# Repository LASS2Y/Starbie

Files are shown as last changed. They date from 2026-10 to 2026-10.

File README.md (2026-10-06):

# Starbie

A tiny motion-controlled digital pet, basically a desktop Tamagotchi. Totally not a Starboy.

Starbie lives on a small PCB built around a Seeed Studio XIAO ESP32-C3. It shows its face and mood on a 0.96" OLED screen, reacts when you tilt or shake it thanks to an MPU6050 accelerometer/gyroscope, notices the temperature and humidity of the room with a DHT11, and you interact with it through two mechanical Cherry MX keys.

This is my starter project for Hack Club's **Half Life** PCB design program.

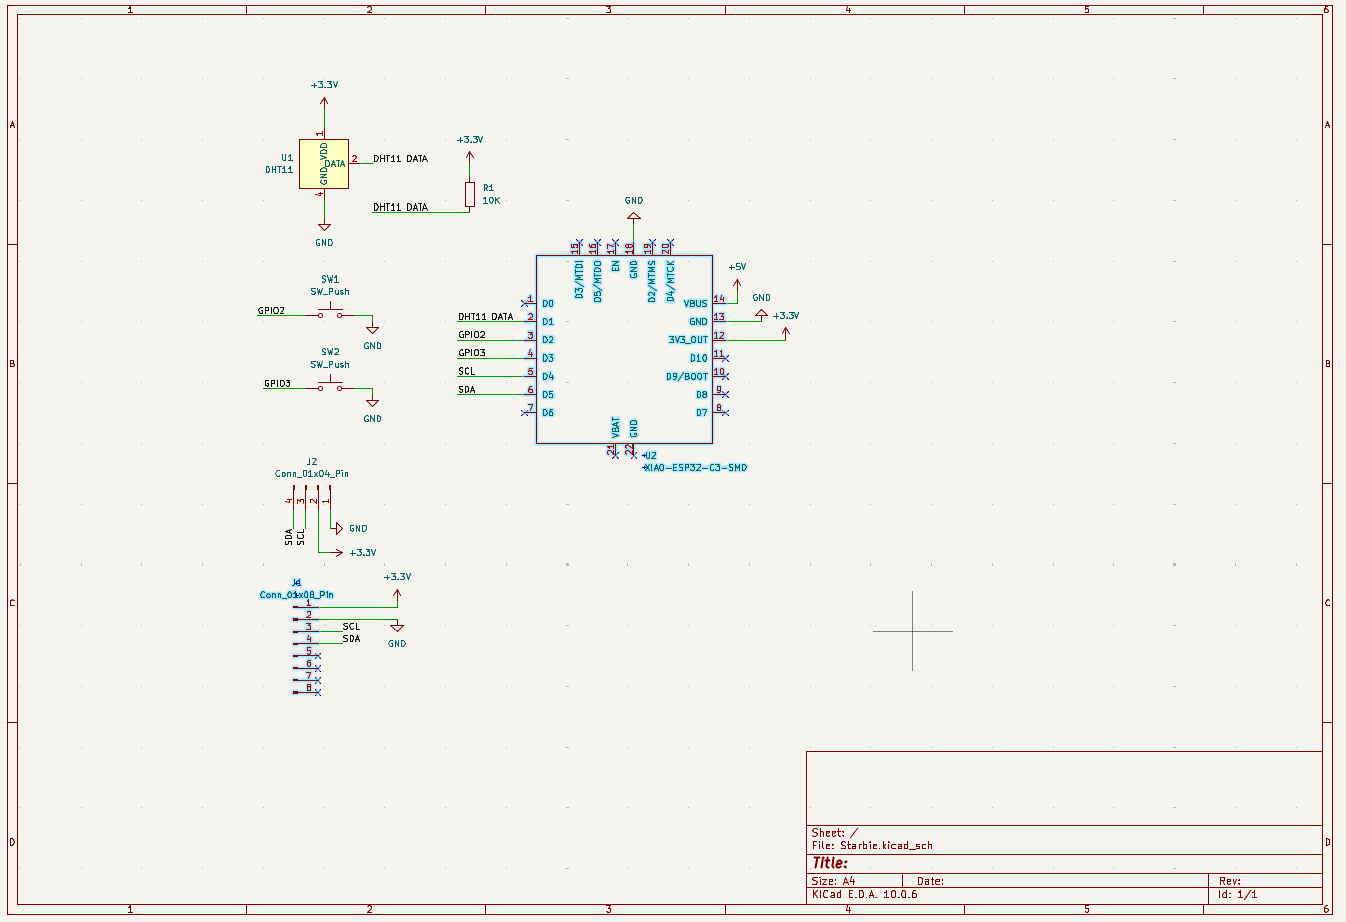
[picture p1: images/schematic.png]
Starbie schematic


## How it works

- **Brain:** the XIAO ESP32-C3 runs the firmware and drives everything.
- **Screen:** the SSD1306 128x64 OLED shares an I2C bus with the MPU6050.
- **Motion:** the MPU6050 detects tilts, shakes and taps. That's how you play with Starbie.
- **Environment:** the DHT11 measures temperature and humidity, so Starbie can tell when it's too hot or too cold.
- **Buttons:** two Cherry MX switches for feeding, playing and navigating menus.
- **Power:** USB-C through the XIAO.

## Pinout

| XIAO pin | Connected to |
|---|---|
| D1 | DHT11 data (10 kΩ pull-up to 3.3V) |
| D2 | SW1 (to GND) |
| D3 | SW2 (to GND) |
| D4 / SDA | OLED + MPU6050 SDA |
| D5 / SCL | OLED + MPU6050 SCL |
| 3V3 | OLED, MPU6050, DHT11 |
| GND | Common ground |

The buttons pull the pin to GND when pressed, so the firmware uses the ESP32's internal pull-ups.

## Bill of materials

| Ref | Part | Qty |
|---|---|---|
| U2 | Seeed Studio XIAO ESP32-C3 | 1 |
| J2 | 0.96" SSD1306 OLED, 128x64, I2C | 1 |
| J1 | GY-521 MPU6050 module (1x08 header) | 1 |
| U1 | DHT11 temperature & humidity sensor | 1 |
| SW1, SW2 | Cherry MX switch + DSA keycap | 2 |
| R1 | 10 kΩ resistor (THT) | 1 |

## Repository layout

```
Starbie.kicad_pro     KiCad project
Starbie.kicad_sch     Schematic
Starbie.kicad_pcb     PCB layout
Week 1 Care Package/  Symbols, footprints and 3D models used by the project
firmware/             Firmware (coming soon)
images/               Screenshots (PCB render coming once routing is done)
```

## Status

- [x] Schematic
- [x] Footprints assigned
- [ ] Board outline and component placement
- [ ] Routing
- [ ] 3D render
- [ ] Firmware
- [ ] Fabrication files (Gerbers)

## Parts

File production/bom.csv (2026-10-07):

Reference | Qty | Value | DNP | Exclude from BOM | Exclude from Board | Exclude from Simulation | Exclude from Position Files | Footprint | Datasheet
J1 | 1 | Conn_01x08_Pin |  |  |  |  | ${EXCLUDE_FROM_POS_FILES} | Connector_PinHeader_2.54mm:PinHeader_1x08_P2.54mm_Vertical
J2 | 1 | Conn_01x04_Pin |  |  |  |  | ${EXCLUDE_FROM_POS_FILES} | Imported Parts:Display_128x64_096_I2C
R1 | 1 | 10K |  |  |  |  | ${EXCLUDE_FROM_POS_FILES} | Resistor_THT:R_Axial_DIN0204_L3.6mm_D1.6mm_P7.62mm_Horizontal
SW1,SW2 | 2 | SW_Push |  |  |  |  | ${EXCLUDE_FROM_POS_FILES} | Button_Switch_Keyboard:SW_Cherry_MX_1.00u_PCB
U1 | 1 | DHT11 |  |  |  |  | ${EXCLUDE_FROM_POS_FILES} | Sensor:Aosong_DHT11_5.5x12.0_P2.54mm | http://akizukidenshi.com/download/ds/aosong/DHT11.pdf
U2 | 1 | XIAO-ESP32-C3-SMD |  |  |  |  | ${EXCLUDE_FROM_POS_FILES} | Imported Parts:XIAO-ESP32-C6-DIP

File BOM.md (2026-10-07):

# Starbie — bill of materials

<!-- Generated by Half Life from project cmuv4g8x80dem01smvfayf5wf. Edits here are overwritten on the next sync. -->
<!-- Generated: 2026-10-07T19:32:48.326Z -->

> [!NOTE]
> This parts list is mirrored from [Half Life](https://halflife.hackclub.com). Editing it here will not change the platform's copy, and the next sync overwrites this file.

| Week | Tier | Parts funding |
| --- | --- | --- |
| Week 1 | Tier 1 | $30.00 |

| Part | What it's for | Qty | Unit | Total | Vendor |
| --- | --- | --- | --- | --- | --- |
| Conn_01x08_Pin | — | 1 | $0.00 | $0.00 | — |
| Conn_01x04_Pin | — | 1 | $0.00 | $0.00 | — |
| 10K | — | 1 | $0.00 | $0.00 | — |
| SW_Push | — | 2 | $0.00 | $0.00 | — |
| DHT11 | — | 1 | $0.00 | $0.00 | — |
| XIAO-ESP32-C3-SMD | — | 1 | $0.00 | $0.00 | — |
| **Parts subtotal** | — | — | — | **$0.00** | — |
| **Tax & shipping** | — | — | — | **$0.00** | — |
| **Total** | — | — | — | **$0.00** | — |

$30.00 left of the tier's funding.

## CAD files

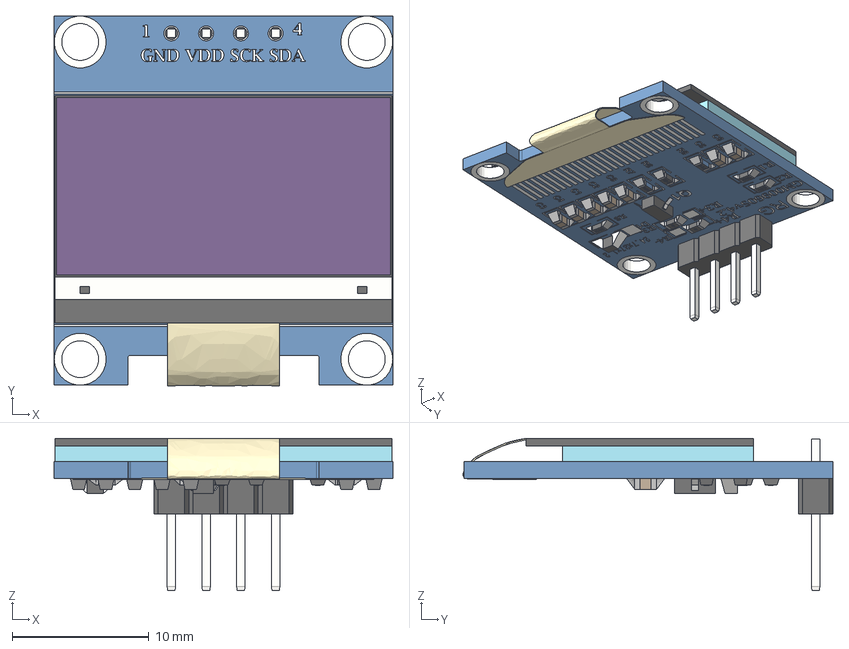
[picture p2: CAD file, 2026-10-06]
Week 1 Care Package/3D Models/0.96'' OLED Display.step
24.8 x 27.1 x 11.1 mm

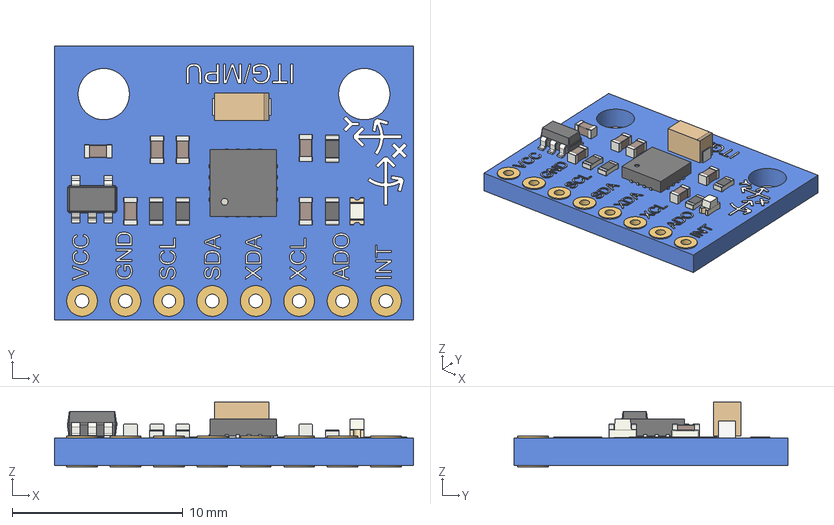
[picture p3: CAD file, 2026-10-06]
Week 1 Care Package/3D Models/GY-521_MPU6050 Accelerometer.step
21.0 x 16.0 x 3.80 mm
PCB
trou1
trou002
trou003
trou004
trou005
trou006
trou007
trou008
Text_X
Symb_Y
Symb_X
Text_Y
Text_VCC
Text_GND
Text_SCL
Text_SDA
Text_XDA
Text_XCL
Text_ADO
Text_INT
R_0603_1608Metric
R_0603_1608Metric001
R_0603_1608Metric002
R_0603_1608Metric003
C_0603_1608Metric
C_0603_1608Metric001
C_0603_1608Metric002
C_0603_1608Metric003
Corps002
Corps001 (Mirror #1)
C_0603_1608Metric004
C_0603_1608Metric005
LED_0603_1608Metric_Castellated
QFN_16_1EP_4x4mm_P065mm_EP21x21mm
Text_ITGMPU
SOT_23_5
Corps001

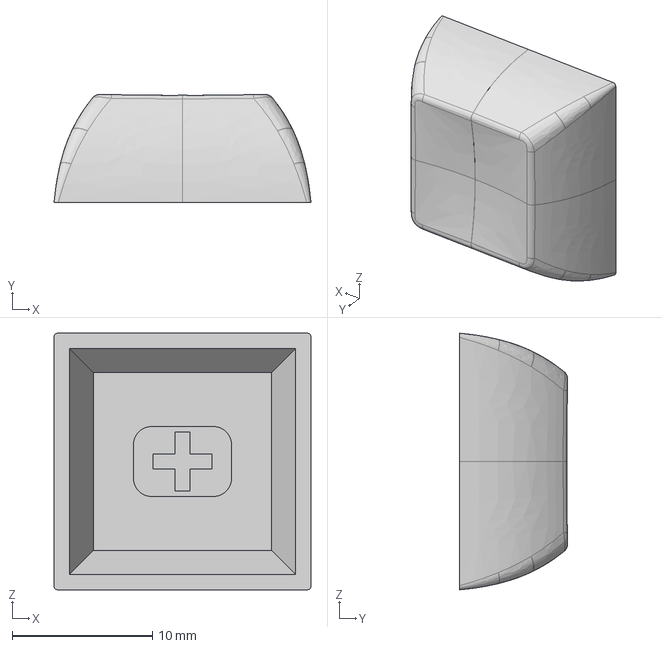
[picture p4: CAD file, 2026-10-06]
Week 1 Care Package/3D Models/DSA_Keycap_CherryMX.step
18.3 x 7.69 x 18.3 mm

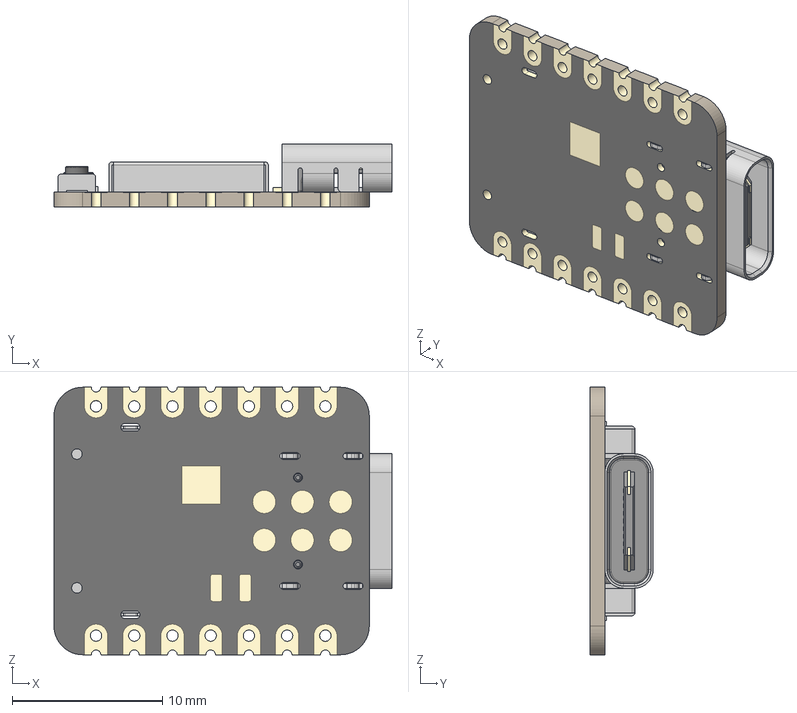
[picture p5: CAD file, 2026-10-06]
Week 1 Care Package/3D Models/Seeed Studio XIAO-ESP32-C3.step
22.5 x 4.21 x 17.8 mm
BOSS-EXTRUDE14_8_
BOSS-EXTRUDE7_4_
BOSS-EXTRUDE7_3_
BOSS-EXTRUDE14_4_
BOSS-EXTRUDE14_2_
BOSS-EXTRUDE14_11_
BOSS-EXTRUDE7_7_
BOSS-EXTRUDE14_9_
BOSS-EXTRUDE14_3_
BOSS-EXTRUDE14_7_
MIRROR2
BOSS-EXTRUDE14_5_
BOSS-EXTRUDE14_12_
BOSS-EXTRUDE7_8_
BOSS-EXTRUDE7_1_
BOSS-EXTRUDE14_10_
BOSS-EXTRUDE7_9_
BOSS-EXTRUDE14_6_
BOSS-EXTRUDE14_1_
BOSS-EXTRUDE7_6_
BOSS-EXTRUDE7_2_
CUT-EXTRUDE5
BOSS-EXTRUDE7_5_
U.FL Connector v1
Button (1) x 2
Shield

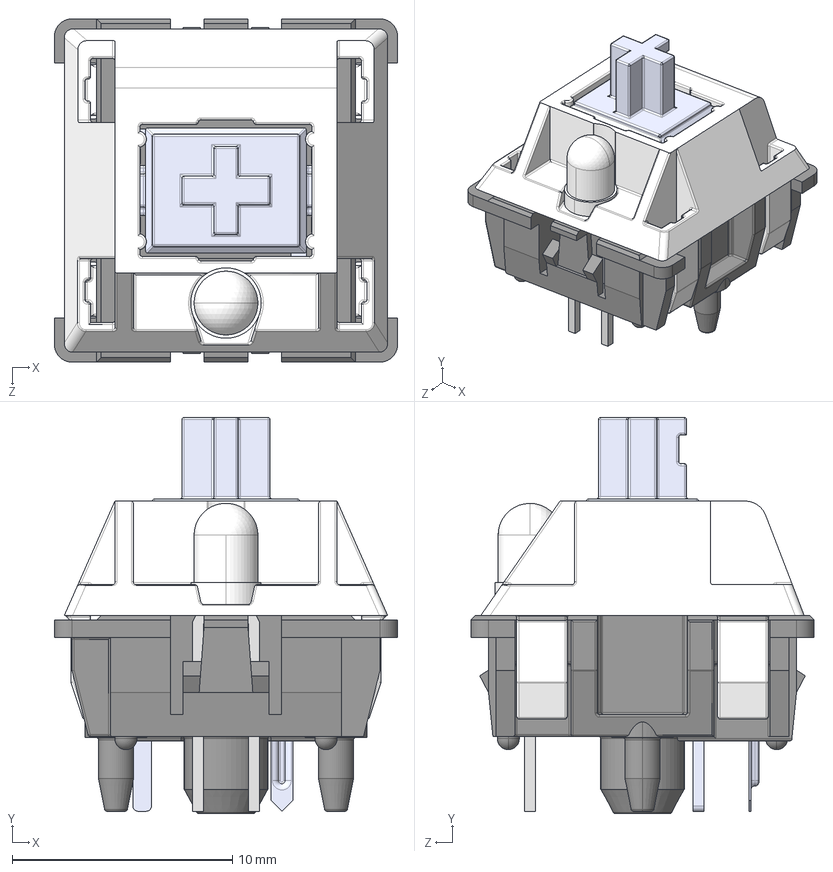
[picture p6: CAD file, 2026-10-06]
Week 1 Care Package/3D Models/Cherry MX.STEP
15.6 x 18.0 x 15.6 mm
Bottom
Pulsador
Top
Pieza5^Cherry MX
Pin1
Pin2
Led 3mm_trans

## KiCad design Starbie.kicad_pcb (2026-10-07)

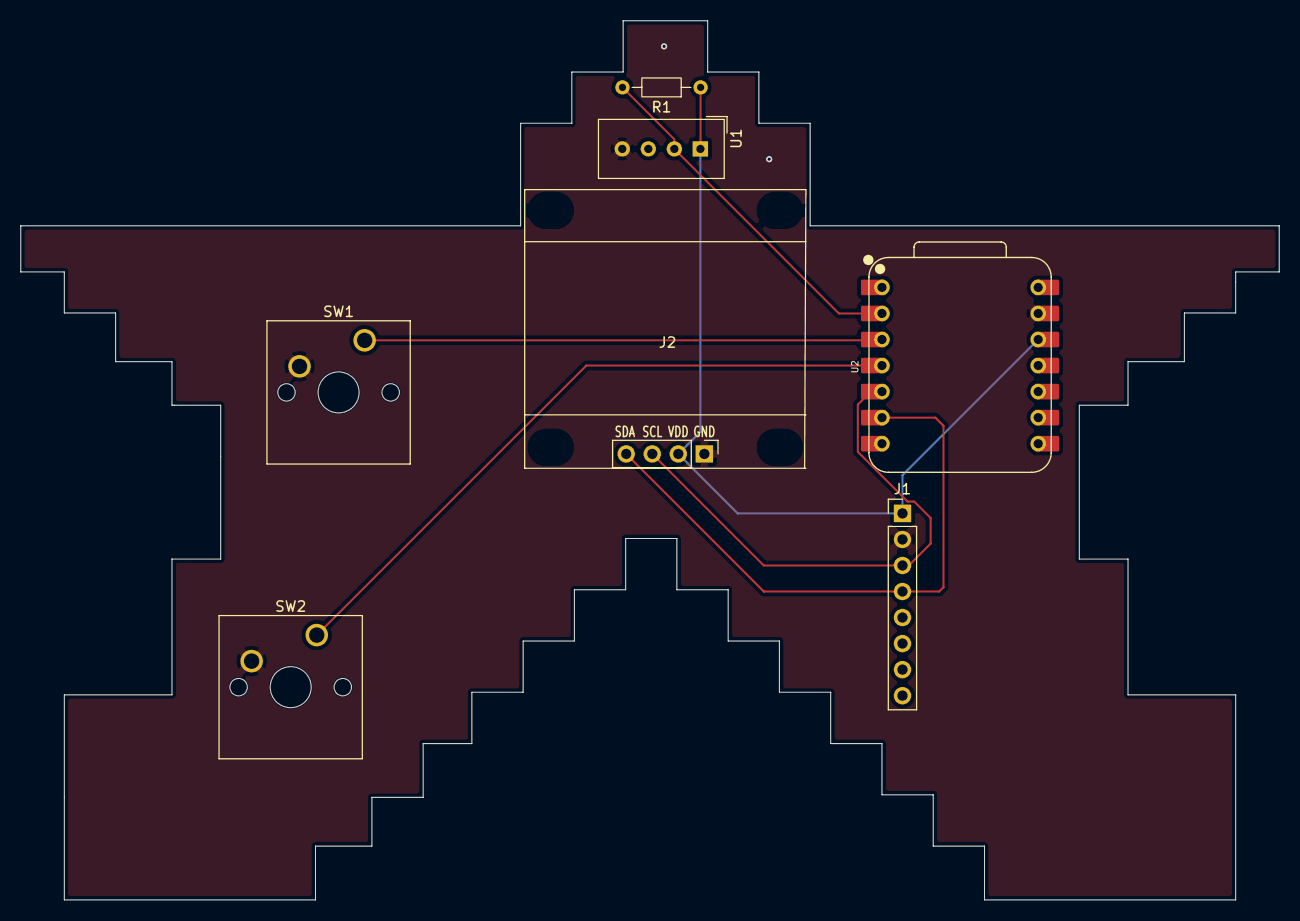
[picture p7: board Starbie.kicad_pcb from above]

Board: 2 copper layers, 122.8 x 85.8 mm, 7 parts (0 on the bottom side), 7 nets.

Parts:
J1: Conn_01x08_Pin; PinHeader_1x08_P2.54mm_Vertical
J2: Conn_01x04_Pin; Display_128x64_096_I2C
R1: 10K; R_Axial_DIN0204_L3.6mm_D1.6mm_P7.62mm_Horizontal
SW1, SW2: SW_Push; SW_Cherry_MX_1.00u_PCB
U1: DHT11; Aosong_DHT11_5.5x12.0_P2.54mm
U2: XIAO-ESP32-C3-SMD; XIAO-ESP32-C6-DIP

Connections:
+3.3V: J1.1, J2.2, R1.1, U1.1 (VDD), U2.12 (3V3_OUT)
/DHT11 DATA: R1.2, U1.2 (DATA), U2.2 (D1)
/GPIO2: SW1.1, U2.3 (D2)
/GPIO3: SW2.1, U2.4 (D3)
/SCL: J1.3, J2.3, U2.5 (D4)
/SDA: J1.4, J2.4, U2.6 (D5)
GND: J1.2, J2.1, SW1.2, SW2.2, U1.4 (GND), U2.13 (GND)

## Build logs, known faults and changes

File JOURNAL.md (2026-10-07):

# Starbie — devlog

<!-- Generated by Half Life from project cmuv4g8x80dem01smvfayf5wf. Edits here are overwritten on the next sync. -->
<!-- Generated: 2026-10-07T19:57:04.020Z -->

> [!NOTE]
> This devlog is mirrored from [Half Life](https://halflife.hackclub.com). Editing it here will not change the platform's copy, and the next sync overwrites this file.

> A tiny motion-controlled digital pet, basically a desktop Tamagotchi. Totally not a Starboy.

| Week | Tier | Hours logged | Entries |
| --- | --- | --- | --- |
| Week 1 | Tier 1 | 4.95h | 3 |

## Contents

1. [2026-10-07 — Routing finished, DRC cleanup & Arduino IDE setup](#2026-10-07-routing-finished-drc-cleanup-arduino-ide-setup)
2. [2026-10-07 — DRC fixed, first look at the firmware, Gerbers & BOM exported](#2026-10-07-drc-fixed-first-look-at-the-firmware-gerbers-bom-)
3. [2026-10-07 — ##Catching up: unrecorded work from my first sessions](#2026-10-07-catching-up-unrecorded-work-from-my-first-session)

## Design

### 2026-10-07 — Routing finished, DRC cleanup & Arduino IDE setup

**0.83h**

Routing finished, DRC cleanup & Arduino IDE setup

Hi, I'm Lincoln and I'm building Starbie, a tiny motion-controlled desktop pet (basically a Tamagotchi) for the Half Life starter project.

Quick context: I was so excited about this project that I just read the guide on GitHub and jumped straight into KiCad without exploring the Half Life site first. In that first session I did the whole schematic (importing the care package libraries, assigning footprints) and started the PCB: star-shaped board outline and component placement. I didn't know about Lapse yet, so that session wasn't recorded. After that I learned how journaling and timelapses work here, so from now on every session gets recorded.

What I did today (recorded):
- Finished the PCB routing (0 unconnected items in the DRC )
- Worked through the DRC violations: a malformed courtyard on the OLED footprint (J2)
- Set up the Arduino IDE for the XIAO ESP32-C3 following the guide and added the firmware sketch to the repo. I can't upload it yet since I don't have the board, but it compiles

Next:
fix the remaining DRC errors, export the 3D render and the Gerbers, then start working on the firmware.

Capture d'écran 2026-10-07 200116

Capture d'écran 2026-10-07 200238

[Timelapse](https://lookout.hackclub.com/api/media/dac7c358-3f88-421e-8c8a-101437cc0d59/video.mp4)

[Timelapse](https://lookout.hackclub.com/api/media/0ea7047d-b525-4c03-b1d7-52ee374e575a/video.mp4)

### 2026-10-07 — DRC fixed, first look at the firmware, Gerbers & BOM exported

**1.12h**

DRC fixed, first look at the firmware, Gerbers & BOM exported

I started this session by fixing the other main DRC error on my PCB . Then I played around with
the firmware a bit to understand how it works. I can't upload it yet since
I don't have the XIAO ESP32-C3, but I wanted to get familiar with the code
before the board arrives.

After that I generated the Gerbers and drill files, exported the BOM as a
CSV, and pushed everything to my GitHub repo for Half Life.

Next: render the board in 3D and start writing my own firmware for Starbie.

Capture d'écran 2026-10-07 212559

Capture d'écran 2026-10-07 212936

[Timelapse](https://lookout.hackclub.com/api/media/34e4aa33-3807-4683-aedb-9ee2bf594cd3/video.mp4)

### 2026-10-07 — ##Catching up: unrecorded work from my first sessions

**3h**

##Catching up: unrecorded work from my first sessions

In this entry I'm logging the work I did before I started recording with Lapse, so it couldn't be filmed.

Sorry about that: I hadn't read the docs all the way through, so I didn't know Lapse was the way to track hardware work. I lost quite a lot of time trying to track my KiCad hours with Hackatime and the kicad-wakatime extension, but it didn't work properly (it only sent heartbeats when I saved, so most of my time wasn't counted, like just 2 min was recorder). Then I read the journaling docs and understood that Lapse was the solution. Every session from now on is recorded.

**Discovering the project.** I went through the Starbie guide on GitHub and downloaded the Week 1 care package.

**Repository setup.** I created the GitHub repo, wrote a README with a schematic screenshot, set up a `.gitignore` for KiCad's temporary files, and connected the repo to Half Life.

**Schematic.** I added the care package libraries to my KiCad project (symbols and the `Imported Parts.pretty` footprints) and drew the schematic: XIAO ESP32-C3, OLED and MPU6050 on I2C, DHT11 with a 10k pull-up, and two Cherry MX switches. I replaced `SW_MEC_5G` with `SW_Push` because it had 4 pins for a 2-pad footprint.

**PCB.** I assigned the footprints, fixed the "footprint not found" errors by adding the footprint library, then drew the star-shaped board outline, placed the components and made a first GND ground plane.

guide, repo setup, schematic, footprints, board outline and placement, all done before I was recording.

**Next:** since the 3D part starts in week 2, I'll keep improving and personalizing my PCB, then work on the firmware to customize my Tamagotchi.

Capture d'écran 2026-10-07 214918

Capture d'écran 2026-10-07 214952

Capture d'écran 2026-10-07 215139

Capture d'écran 2026-10-07 215246

Capture d'écran 2026-10-07 215343

Capture d'écran 2026-10-07 215617

Capture d'écran 2026-10-07 215600

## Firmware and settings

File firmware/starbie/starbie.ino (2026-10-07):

/*
  Starbie: a tiny motion-controlled digital pet

  This is intentionally one file. Open this .ino file in Arduino IDE, edit
  the BEGINNER SETTINGS section, and upload it to a Seeed XIAO ESP32-C3.

  Install these libraries with Sketch > Include Library > Manage Libraries:
    - Adafruit GFX Library
    - Adafruit SSD1306
    - Adafruit MPU6050
    - DHT sensor library
  Arduino IDE will offer to install their dependencies too. Click Install All.
*/

#include <Wire.h>
#include <Adafruit_GFX.h>
#include <Adafruit_SSD1306.h>
#include <Adafruit_MPU6050.h>
#include <DHT.h>
#include <Preferences.h>
#include <math.h>

// =========================== BEGINNER SETTINGS ===========================
// Everything most builders will want to customize is in this one section.

// --- Your board's pins ----------------------------------------------------
// These are ESP32-C3 GPIO numbers, with the XIAO pin labels beside them.
const int I2C_SDA_PIN = 6;       // XIAO D4: OLED + MPU6050 SDA
const int I2C_SCL_PIN = 7;       // XIAO D5: OLED + MPU6050 SCL
const int DHT_PIN = 3;           // XIAO D1: DHT11 data
const int BUTTON_ONE_PIN = 4;    // XIAO D2: opens/confirms the radial menu
const int BUTTON_TWO_PIN = 5;    // XIAO D3: shows/hides stats

// Set this to false if your submission does not have a DHT11.
const bool USE_DHT11 = true;

// Most parts use these addresses. Only change them if an I2C scanner says
// your part is different (common OLED alternative: 0x3D).
const uint8_t OLED_ADDRESS = 0x3C;
const uint8_t MPU6050_ADDRESS = 0x68;

// --- Starting stats -------------------------------------------------------
// Stats are 0 to 100. They only change when you select an action or shake
// Starbie; nothing slowly drains while it sits on your desk.
const int STARTING_JOY = 70;
const int STARTING_ENERGY = 75;
const int STARTING_FULLNESS = 65;

// Set true, upload once, then set it back to false if you want a fresh pet.
const bool RESET_SAVED_PET_ON_BOOT = false;

// --- Radial menu ----------------------------------------------------------
// These four actions appear at TOP, RIGHT, BOTTOM, then LEFT in the menu.
// The last word controls the matching little visual reaction.
enum PetReaction {
  NAP_REACTION,
  JUMP_REACTION,
  HEART_REACTION,
  RUN_REACTION,
};

struct MenuItem {
  const char *label;
  int joyChange;
  int energyChange;
  int fullnessChange;
  PetReaction reaction;
};

const MenuItem MENU_ITEMS[] = {
  {"NAP",   1,  18, -4, NAP_REACTION},   // top: sleep and emit Zs
  {"PLAY", 12, -9, -5, RUN_REACTION},    // right: two fast laps + hearts
  {"FEED",  3,  2,  18, JUMP_REACTION},  // bottom: wiggle and jump
  {"PET",   7,  0,  0, HEART_REACTION},  // left: jump and emit hearts
};
const int MENU_ITEM_COUNT = sizeof(MENU_ITEMS) / sizeof(MENU_ITEMS[0]);

// --- Movement feel --------------------------------------------------------
// Bigger MENU_TILT_LIMIT makes the menu ball move less.
const float MENU_TILT_LIMIT = 6.0f;

// MPU6050 orientation: change these settings instead of rewiring your board.
// 1. If the sensor is turned 90 degrees, set SWAP_MPU_AXES to true.
// 2. If a direction feels backwards, change that direction from 1.0f to -1.0f.
const bool SWAP_MPU_AXES = false;
const float MENU_X_DIRECTION = 1.0f;
const float MENU_Y_DIRECTION = -1.0f;

// A small dead zone makes the ball rest in the center until the board is tilted.
const float MENU_CENTER_DEADZONE = 0.8f;
const float SHAKE_THRESHOLD = 7.0f;

// Shake is the only movement that has an effect outside the radial menu.
const int SHAKE_JOY_CHANGE = 5;
const int SHAKE_ENERGY_CHANGE = -2;
const int SHAKE_FULLNESS_CHANGE = -1;

// --- Your pet's bitmap and animation -------------------------------------
// This is a simplified 32 by 32, one-bit version of the supplied character.
// You can replace it with your own art later; keep these size values matched
// to the sprite array you paste in.
const int PET_SPRITE_WIDTH = 32;
const int PET_SPRITE_HEIGHT = 32;

// The pet wanders unless it is asleep. A non-nap action does a tiny shake,
// then a jump, except PLAY which runs two fast laps.
const uint16_t PET_WALK_PIXEL_MS = 70;
const uint16_t PET_PRE_JUMP_MS = 230;
const uint16_t PET_JUMP_MS = 430;
const int PET_JUMP_HEIGHT = 16;
const uint32_t NAP_DURATION_MS = 48000;  // 48 seconds: four times the old nap.
const uint16_t HEARTS_DURATION_MS = 1600;
const uint16_t PLAY_LAP_MS = 800;
const uint8_t PLAY_LAP_COUNT = 2;

// Each byte stores eight pixels, left to right. This sparse outline keeps the
// supplied creature readable on a tiny, one-bit OLED: head, eye, legs, tail,
// and a small flower-like ear accent all stay separate instead of becoming a blob.
const uint8_t PROGMEM PET_SPRITE[] = {
  0x00, 0x00, 0x00, 0x00,
  0x00, 0x00, 0x00, 0x00,
  0x00, 0x00, 0x00, 0x00,
  0x00, 0x00, 0x00, 0x00,
  0x00, 0x00, 0x00, 0x00,
  0x00, 0x00, 0x00, 0x00,
  0x00, 0x70, 0x0a, 0x00,
  0x00, 0xf8, 0x1f, 0x00,
  0x00, 0x8c, 0x3f, 0x80,
  0x00, 0x43, 0xff, 0x00,
  0x00, 0x43, 0xff, 0x00,
  0x00, 0x30, 0x7e, 0x00,
  0x00, 0x98, 0x01, 0x00,
  0x01, 0x98, 0x01, 0x80,
  0x03, 0x00, 0x10, 0xc0,
  0x03, 0x04, 0x00, 0xc0,
  0x01, 0x8b, 0x01, 0x80,
  0x01, 0xcb, 0x03, 0x80,
  0x03, 0xc0, 0x03, 0xc0,
  0x03, 0xc0, 0x03, 0xc0,
  0x01, 0xc0, 0x03, 0x80,
  0x01, 0x80, 0x01, 0x80,
  0x00, 0x60, 0x06, 0x00,
  0x00, 0x3f, 0xfc, 0x00,
  0x00, 0x7f, 0xfe, 0x00,
  0x00, 0x70, 0x0e, 0x00,
  0x00, 0x00, 0x00, 0x00,
  0x00, 0x00, 0x00, 0x00,
  0x00, 0x00, 0x00, 0x00,
  0x00, 0x00, 0x00, 0x00,
  0x00, 0x00, 0x00, 0x00,
  0x00, 0x00, 0x00, 0x00,
};
// ===========================================================================
// You can read below without needing to understand every line. The rest of
// the sketch handles buttons, sensors, drawing, and saving automatically.

const int SCREEN_WIDTH = 128;
const int SCREEN_HEIGHT = 64;
const int MENU_CENTER_X = 64;
const int MENU_CENTER_Y = 32;
const int MENU_ITEM_X[] = {64, 108, 64, 20};
const int MENU_ITEM_Y[] = {12, 32, 53, 32};
const int MENU_BALL_X_RANGE = 37;
const int MENU_BALL_Y_RANGE = 22;
const uint16_t BUTTON_DEBOUNCE_MS = 30;
const uint16_t MPU_READ_INTERVAL_MS = 30;
const uint16_t DHT_READ_INTERVAL_MS = 2200;
const uint16_t SHAKE_COOLDOWN_MS = 650;
const float STANDARD_GRAVITY = 9.80665f;

Adafruit_SSD1306 display(SCREEN_WIDTH, SCREEN_HEIGHT, &Wire, -1);
Adafruit_MPU6050 mpu;
DHT dht(DHT_PIN, DHT11);
Preferences preferences;

struct PetState {
  int joy;
  int energy;
  int fullness;
};

struct ButtonState {
  int pin;
  bool stableState;
  bool lastRawState;
  uint32_t lastChangedAt;
};

enum View {
  PET_VIEW,
  MENU_VIEW,
  STATS_VIEW,
};

PetState pet = {STARTING_JOY, STARTING_ENERGY, STARTING_FULLNESS};
ButtonState buttonOne = {BUTTON_ONE_PIN, HIGH, HIGH, 0};
ButtonState buttonTwo = {BUTTON_TWO_PIN, HIGH, HIGH, 0};
View currentView = PET_VIEW;

bool mpuFound = false;
bool dhtFound = false;
float accelerationX = 0.0f;
float accelerationY = 0.0f;
float accelerationZ = STANDARD_GRAVITY;
float temperatureC = NAN;
float humidity = NAN;
float menuBallX = MENU_CENTER_X;
float menuBallY = MENU_CENTER_Y;
float menuCenterAccelerationX = 0.0f;
float menuCenterAccelerationY = 0.0f;
int selectedMenuItem = -1;
uint32_t lastMpuReadAt = 0;
uint32_t lastDhtReadAt = 0;
uint32_t lastShakeAt = 0;
uint32_t shakeAnimationEndsAt = 0;
uint32_t petJumpStartedAt = 0;
uint32_t nappingUntil = 0;
uint32_t heartAnimationEndsAt = 0;
uint32_t playRunStartedAt = 0;
int nappingPetX = 0;

int petWalkingX(uint32_t now);

int keepInRange(int value, int smallest, int largest) {
  return constrain(value, smallest, largest);
}

void changePet(int joyChange, int energyChange, int fullnessChange) {
  pet.joy = keepInRange(pet.joy + joyChange, 0, 100);
  pet.energy = keepInRange(pet.energy + energyChange, 0, 100);
  pet.fullness = keepInRange(pet.fullness + fullnessChange, 0, 100);
}

void loadPet() {
  preferences.begin("starbie", false);
  if (RESET_SAVED_PET_ON_BOOT) {
    preferences.clear();
  }
  pet.joy = preferences.getInt("joy", STARTING_JOY);
  pet.energy = preferences.getInt("energy", STARTING_ENERGY);
  pet.fullness = preferences.getInt("full", STARTING_FULLNESS);
}

void savePet() {
  preferences.putInt("joy", pet.joy);
  preferences.putInt("energy", pet.energy);
  preferences.putInt("full", pet.fullness);
}

void setUpButton(ButtonState &button) {
  pinMode(button.pin, INPUT_PULLUP);
  button.stableState = digitalRead(button.pin);
  button.lastRawState = button.stableState;
  button.lastChangedAt = millis();
}

// Returns true exactly once for each press, even if the switch bounces.
bool wasPressed(ButtonState &button) {
  const bool rawState = digitalRead(button.pin);
  const uint32_t now = millis();

  if (rawState != button.lastRawState) {
    button.lastRawState = rawState;
    button.lastChangedAt = now;
  }

  if (rawState != button.stableState &&
      now - button.lastChangedAt >= BUTTON_DEBOUNCE_MS) {
    button.stableState = rawState;
    return button.stableState == LOW;
  }

  return false;
}

void updateMpu() {
  if (!mpuFound || millis() - lastMpuReadAt < MPU_READ_INTERVAL_MS) {
    return;
  }
  lastMpuReadAt = millis();

  sensors_event_t acceleration;
  sensors_event_t gyro;
  sensors_event_t sensorTemperature;
  mpu.getEvent(&acceleration, &gyro, &sensorTemperature);
  accelerationX = acceleration.acceleration.x;
  accelerationY = acceleration.acceleration.y;
  accelerationZ = acceleration.acceleration.z;
}

void updateDht() {
  if (!dhtFound || millis() - lastDhtReadAt < DHT_READ_INTERVAL_MS) {
    return;
  }
  lastDhtReadAt = millis();

  const float newHumidity = dht.readHumidity();
  const float newTemperatureC = dht.readTemperature();
  if (!isnan(newHumidity)) {
    humidity = newHumidity;
  }
  if (!isnan(newTemperatureC)) {
    temperatureC = newTemperatureC;
  }
}

int petWalkingX(uint32_t now) {
  const int farthestX = SCREEN_WIDTH - PET_SPRITE_WIDTH;
  const uint32_t roundTrip = static_cast<uint32_t>(farthestX) * 2;
  const uint32_t step = (now / PET_WALK_PIXEL_MS) % roundTrip;
  return step <= farthestX ? step : roundTrip - step;
}

uint32_t playRunDuration() {
  return static_cast<uint32_t>(PLAY_LAP_MS) * PLAY_LAP_COUNT;
}

bool isNapping() {
  return nappingUntil != 0 && millis() < nappingUntil;
}

bool isPlaying() {
  return playRunStartedAt != 0 && millis() - playRunStartedAt < playRunDuration();
}

int playRunX(uint32_t now) {
  const int farthestX = SCREEN_WIDTH - PET_SPRITE_WIDTH;
  const uint32_t lapAge = (now - playRunStartedAt) % PLAY_LAP_MS;
  const float progress = static_cast<float>(lapAge) / PLAY_LAP_MS;
  return progress < 0.5f ? static_cast<int>(progress * 2.0f * farthestX)
                         : static_cast<int>((1.0f - progress) * 2.0f * farthestX);
}

void updatePetTimers() {
  if (nappingUntil != 0 && !isNapping()) {
    nappingUntil = 0;  // The pet wakes naturally when its nap time is over.
  }
  if (playRunStartedAt != 0 && !isPlaying()) {
    playRunStartedAt = 0;  // PLAY is exactly two left-to-right-to-left laps.
  }
}

// While the menu is open, the MPU6050 acts like a tiny air mouse. The position
// at the instant Button 1 opens the menu becomes the center for that menu use.
void updateMenuBall() {
  float xTilt = accelerationX - menuCenterAccelerationX;
  float yTilt = accelerationY - menuCenterAccelerationY;

  if (SWAP_MPU_AXES) {
    const float oldXTilt = xTilt;
    xTilt = yTilt;
    yTilt = oldXTilt;
  }
  xTilt = constrain(xTilt * MENU_X_DIRECTION, -MENU_TILT_LIMIT, MENU_TILT_LIMIT);
  yTilt = constrain(yTilt * MENU_Y_DIRECTION, -MENU_TILT_LIMIT, MENU_TILT_LIMIT);
  const float targetX = MENU_CENTER_X + (xTilt / MENU_TILT_LIMIT) * MENU_BALL_X_RANGE;
  const float targetY = MENU_CENTER_Y + (yTilt / MENU_TILT_LIMIT) * MENU_BALL_Y_RANGE;

  // This small amount of smoothing makes the ball feel less jittery.
  menuBallX += (targetX - menuBallX) * 0.20f;
  menuBallY += (targetY - menuBallY) * 0.20f;

  // The menu has four full sectors, not four tiny targets. Any tilt direction
  // past the center dead zone selects its matching top/right/bottom/left action.
  if (fabsf(xTilt) < MENU_CENTER_DEADZONE && fabsf(yTilt) < MENU_CENTER_DEADZONE) {
    selectedMenuItem = -1;
  } else if (fabsf(xTilt) > fabsf(yTilt)) {
    selectedMenuItem = xTilt > 0.0f ? 1 : 3;  // right or left
  } else {
    selectedMenuItem = yTilt > 0.0f ? 2 : 0;  // bottom or top
  }
}

void checkForShake() {
  if (!mpuFound || currentView != PET_VIEW) {
    return;
  }

  const float magnitude = sqrtf(accelerationX * accelerationX +
                                accelerationY * accelerationY +
                                accelerationZ * accelerationZ);
  const uint32_t now = millis();
  if (fabsf(magnitude - STANDARD_GRAVITY) >= SHAKE_THRESHOLD &&
      now - lastShakeAt >= SHAKE_COOLDOWN_MS) {
    lastShakeAt = now;
    nappingUntil = 0;  // A shake wakes a sleeping pet right away.
    shakeAnimationEndsAt = now + 350;
    changePet(SHAKE_JOY_CHANGE, SHAKE_ENERGY_CHANGE, SHAKE_FULLNESS_CHANGE);
    savePet();
  }
}

void openMenu() {
  currentView = MENU_VIEW;
  selectedMenuItem = -1;
  menuBallX = MENU_CENTER_X;
  menuBallY = MENU_CENTER_Y;
  // Calibrate here so every menu starts from however the builder is holding it.
  menuCenterAccelerationX = accelerationX;
  menuCenterAccelerationY = accelerationY;
}

void chooseMenuItem() {
  if (selectedMenuItem == -1) {
    return;  // Keep the menu open until the ball reaches a choice.
  }

  const MenuItem &item = MENU_ITEMS[selectedMenuItem];
  changePet(item.joyChange, item.energyChange, item.fullnessChange);
  savePet();
  const uint32_t now = millis();
  nappingUntil = 0;
  heartAnimationEndsAt = 0;
  playRunStartedAt = 0;

  if (item.reaction == NAP_REACTION) {
    petJumpStartedAt = 0;
    nappingPetX = petWalkingX(now);
    nappingUntil = now + NAP_DURATION_MS;
  } else if (item.reaction == RUN_REACTION) {
    petJumpStartedAt = 0;
    playRunStartedAt = now;
    heartAnimationEndsAt = now + playRunDuration();
  } else {
    // A confirmed action gets a little anticipation shake before the jump.
    petJumpStartedAt = now;
    if (item.reaction == HEART_REACTION) {
      heartAnimationEndsAt = now + HEARTS_DURATION_MS;
    }
  }
  currentView = PET_VIEW;
}

void handleButtons() {
  if (wasPressed(buttonOne)) {
    if (currentView == MENU_VIEW) {
      chooseMenuItem();
    } else {
      openMenu();
    }
  }

  if (wasPressed(buttonTwo)) {
    // Button 2 never changes the pet. It only lets you peek at the values.
    currentView = currentView == STATS_VIEW ? PET_VIEW : STATS_VIEW;
  }
}

void drawHeart(int x, int y) {
  // A tiny seven-pixel-wide heart that stays crisp on the OLED.
  display.fillRect(x - 2, y, 2, 2, SSD1306_WHITE);
  display.fillRect(x + 1, y, 2, 2, SSD1306_WHITE);
  display.fillRect(x - 3, y + 2, 7, 2, SSD1306_WHITE);
  display.fillRect(x - 2, y + 4, 5, 1, SSD1306_WHITE);
  display.fillRect(x - 1, y + 5, 3, 1, SSD1306_WHITE);
  display.drawPixel(x, y + 6, SSD1306_WHITE);
}

void drawHearts(uint32_t now, int petX, int petY) {
  if (now >= heartAnimationEndsAt) {
    return;
  }

  const float progress =
      1.0f - static_cast<float>(heartAnimationEndsAt - now) / HEARTS_DURATION_MS;
  const int rise = static_cast<int>(progress * 18.0f);
  drawHeart(petX + 10, petY - 3 - rise);
  drawHeart(petX + 22, petY - 9 - rise / 2);
}

void drawSleepZs(uint32_t now, int petX, int petY) {
  // The Zs float upward, then loop back down while the pet is napping.
  const int rise = static_cast<int>((now / 300UL) % 15UL);
  display.setTextSize(1);
  display.setTextColor(SSD1306_WHITE);
  display.setCursor(petX + 23, petY - 2 - rise);
  display.print("z");
  display.setCursor(petX + 28, petY - 8 - rise / 2);
  display.print("z");
}

void drawPet() {
  display.clearDisplay();

  const uint32_t now = millis();
  int petX = isNapping() ? nappingPetX : petWalkingX(now);
  if (isPlaying()) {
    petX = playRunX(now);
  }
  int petY = SCREEN_HEIGHT - PET_SPRITE_HEIGHT;

  // The pet always wanders except during a nap; PLAY temporarily takes over.
  if (now < shakeAnimationEndsAt) {
    petX += static_cast<int>(sinf(now / 18.0f) * 3.0f);
  }

  if (!isNapping() && petJumpStartedAt != 0) {
    const uint32_t animationAge = now - petJumpStartedAt;

    if (animationAge < PET_PRE_JUMP_MS) {
      petX += static_cast<int>(sinf(now / 16.0f) * 3.0f);
    } else if (animationAge < PET_PRE_JUMP_MS + PET_JUMP_MS) {
      const float jumpProgress =
          static_cast<float>(animationAge - PET_PRE_JUMP_MS) / PET_JUMP_MS;
      petY -= static_cast<int>(sinf(jumpProgress * PI) * PET_JUMP_HEIGHT);
    } else {
      petJumpStartedAt = 0;
    }
  }

  petX = constrain(petX, 0, SCREEN_WIDTH - PET_SPRITE_WIDTH);
  display.drawBitmap(petX, petY, PET_SPRITE, PET_SPRITE_WIDTH, PET_SPRITE_HEIGHT,
                     SSD1306_WHITE);

  if (isNapping()) {
    drawSleepZs(now, petX, petY);
  }
  drawHearts(now, petX, petY);
}

void drawMenuItem(int item) {
  const int boxWidth = 33;
  const int boxHeight = 12;
  const int boxX = MENU_ITEM_X[item] - boxWidth / 2;
  const int boxY = MENU_ITEM_Y[item] - boxHeight / 2;
  const bool isSelected = item == selectedMenuItem;

  if (isSelected) {
    display.fillRoundRect(boxX, boxY, boxWidth, boxHeight, 3, SSD1306_WHITE);
    display.setTextColor(SSD1306_BLACK);
  } else {
    display.drawRoundRect(boxX, boxY, boxWidth, boxHeight, 3, SSD1306_WHITE);
    display.setTextColor(SSD1306_WHITE);
  }

  display.setTextSize(1);
  const int labelLength = strlen(MENU_ITEMS[item].label);
  display.setCursor(MENU_ITEM_X[item] - labelLength * 3, MENU_ITEM_Y[item] - 3);
  display.print(MENU_ITEMS[item].label);
  display.setTextColor(SSD1306_WHITE);
}

void drawMenu() {
  display.clearDisplay();
  // The two diagonal lines divide the screen into four big selection sectors.
  display.drawLine(0, 0, SCREEN_WIDTH - 1, SCREEN_HEIGHT - 1, SSD1306_WHITE);
  display.drawLine(0, SCREEN_HEIGHT - 1, SCREEN_WIDTH - 1, 0, SSD1306_WHITE);
  for (int item = 0; item < MENU_ITEM_COUNT; item++) {
    drawMenuItem(item);
  }

  display.drawCircle(MENU_CENTER_X, MENU_CENTER_Y, 11, SSD1306_WHITE);
  display.fillCircle(static_cast<int>(menuBallX), static_cast<int>(menuBallY), 4,
                     SSD1306_WHITE);
}

void drawStatBar(int y, const char *label, int value) {
  display.setTextSize(1);
  display.setTextColor(SSD1306_WHITE);
  display.setCursor(4, y);
  display.print(label);
  display.drawRect(48, y, 57, 8, SSD1306_WHITE);
  display.fillRect(49, y + 1, map(value, 0, 100, 0, 55), 6, SSD1306_WHITE);
  display.setCursor(109, y);
  display.print(value);
}

void drawStats() {
  display.clearDisplay();
  drawStatBar(5, "JOY", pet.joy);
  drawStatBar(20, "ENERGY", pet.energy);
  drawStatBar(35, "FULL", pet.fullness);

  display.setCursor(4, 53);
  if (!isnan(temperatureC)) {
    display.print("TEMP ");
    display.print(static_cast<int>(temperatureC));
    display.print("C");
  } else {
    display.print("TEMP --");
  }

  display.setCursor(76, 53);
  if (!isnan(humidity)) {
    display.print("H ");
    display.print(static_cast<int>(humidity));
    display.print("%");
  } else {
    display.print("H --");
  }
}

void drawCurrentView() {
  if (currentView == MENU_VIEW) {
    drawMenu();
  } else if (currentView == STATS_VIEW) {
    drawStats();
  } else {
    drawPet();
  }
  display.display();
}

void setup() {
  Serial.begin(115200);
  Wire.begin(I2C_SDA_PIN, I2C_SCL_PIN);
  setUpButton(buttonOne);
  setUpButton(buttonTwo);
  loadPet();

  if (!display.begin(SSD1306_SWITCHCAPVCC, OLED_ADDRESS)) {
    Serial.println("OLED not found. Check power, GND, SDA, SCL, and address.");
    while (true) {
      delay(10);
    }
  }

  mpuFound = mpu.begin(MPU6050_ADDRESS, &Wire);
  if (mpuFound) {
    mpu.setAccelerometerRange(MPU6050_RANGE_8_G);
    mpu.setGyroRange(MPU6050_RANGE_500_DEG);
    mpu.setFilterBandwidth(MPU6050_BAND_21_HZ);
  } else {
    Serial.println("MPU6050 not found. The menu will not move until it is connected.");
  }

  if (USE_DHT11) {
    dht.begin();
    dhtFound = true;
  }

  drawCurrentView();
}

void loop() {
  updateMpu();
  updateDht();
  updatePetTimers();
  handleButtons();

  if (currentView == MENU_VIEW) {
    updateMenuBall();
  } else {
    checkForShake();
  }

  drawCurrentView();
  delay(16);  // Smooth display updates without making the code complicated.
}

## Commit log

2026-10-06 Starbie - Half Life week 1
    [0.96'' OLED Display.step, Cherry MX.STEP, DSA_Keycap_CherryMX.step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]
2026-10-06 Add README, schematic screenshot and .gitignore
2026-10-07 Route PCB and add firmware sketch
    [Starbie.kicad_pcb]
2026-10-07 Add gerbers, drill files and BOM csv format
    [Starbie-B_Cu.gbl, Starbie-B_Mask.gbs, Starbie-B_Paste.gbp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]
2026-10-11 Fix DRC warning errors, add 3D models, render and final Gerbers
